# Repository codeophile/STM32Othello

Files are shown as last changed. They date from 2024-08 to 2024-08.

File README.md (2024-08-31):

# STM32 Othello
Play Othello (also known as Reversi) against the computer with selectable levels of difficulty: "Easy" and "Challenging."

## Features

- Easy to build - not many parts
- Uses inexpensive STM32L412 processor.
- You can build my board (I used JLCPCB) or to avoid soldering surface mount, you can breadboard the whole thing using a NUCLEO-L412KB board ($10.99 at Digikey).
- Uses inexpensive ($3.00 on Aliexpress) 8x8 matrix of WS2812B smart LEDs. 
- Playing Othello is very easy to learn as the rules are super simple. Playing well requires strategy.

## Files

- Hardware folder contains schematic, gerbers, and the Eagle project file. Be aware that Eagle project files were created in Eagle 5.x. I'm not sure if it will open OK in newer versions (it should!).
- Software folder contains all the c code and a README for getting started.

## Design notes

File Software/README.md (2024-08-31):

## Options

- You can just flash the STM32L412 chip with the code file named OthelloL412.elf.
- Or, you can edit and debug it since all the source files are included.

## Editing and debugging the code

This code could be adapted for any IDE, but to use it without having to make changes, you'll need to use STM32CubeIDE which is free from ST.com. If your new to this, check out the excellent 4 part YouTube series on titled "Getting Started with STM32 and Nucleo" (https://www.youtube.com/watch?v=hyZS2p1tW-g).

## Steps

- In STMCube32IDE, create a project using: File/New/STM32 Project from an Existing STM32CubeMX Configuration file (.ioc)
	- Browse to the IOC file. (It doesn’t need to be located anywhere special, any folder location will do since a new copy will be made.)
   	- Enter a project name, select the current workspace folder (default) or designate a new one, and create the project. If asked, select “Migrate”.
- Copy the files from the Inc folder in this repository to your project's Core/Inc
- Copy the files from the Src folder in this repository to your project's Core/Src
- Edit the auto-generated Core/Src/main.c:
	- Find comment line containing "USER CODE BEGIN PFP" and insert below it the line:"void APP_Main();"
	- Find comment line containing "USER CODE BEGIN WHILE" and insert below it the line:"APP_Main();"
 - Build the project

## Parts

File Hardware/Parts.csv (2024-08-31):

QTY | Name | Digikey Part | Manufacturer Part | Desc | Price/comments
1 | IC1 | 497-STM32L412K8T6-ND | STM32L412K8T6 | IC MCU 32BIT 64KB FLASH 32LQFP | Was STM32L412KBT6 has 128KB flash
2 | R1-2 | RMCF0805FT10K0CT-ND | RMCF0805FT10K0 | RES 10K OHM 1% 1/8W 0805
1 | R3 | RMCF0805FT249RCT-ND | RMCF0805FT249R | RES 249 OHM 1% 1/8W 0805
6 | C3-5 | 311-1140-1-ND | CC0805KRX7R9BB104 | CAP CER 0.1UF 50V X7R 0805
2 | C1-2 | 1276-1096-1-ND | CL21A106KOQNNNE | CAP CER 10UF 16V X5R 0805
2 |  | A32918-ND | 5-535541-1 | TE Connectivity AMP Connectors | For LED Matrix. 0.265 height more expensive for this $1.16. S7036-ND is $0.37 but .335 height
 |  | S1211EC-40-ND | PRPC040SFAN-RC | CONN HEADER VERT 40POS 2.54MM | Mates with above. Gold plated. Cut post length to fit
1 | H1 | S9169-ND | SBH11-PBPC-D05-ST-BK | CONN HEADER 10POS 2.54MM
1 | SW0 | CKN9565-ND | OS102011MS2QN1 | SWITCH SLIDE SPDT 100MA 12V | Need non-shorting (BBM) end in N1 rather than S1. Can substitute with "C" on the end (high temp resin)
1 | PB0-7 | CKN10880CT-ND | PTS645SL43SMTR92 LFS | SWITCH TACTILE SPST-NO 0.05A 12V
1 | BAT1 | BK-1280-PC6-ND | BK-1280-PC6 | Battery Holder (Open) AA 3 Cell PC Pin
1 | LED Matrix | https://www.aliexpress.us/item/2251832466712520.html
 |  | Many similar boards are available and will work if they are WS2812B LEDs. To fit PCB, look for those with three 0.1 spaced holes near each corner which are used for pwr, gnd, and io
3 | HD107S LEDS | 50-1000pcs HD107S(Similar APA102) LED Chip 5050 2020 RGB Intelligent Control Integrated LED Light Source APA107S Chip 26+kHz PWM - AliExpress 39
 |  | Can substitute SK9822

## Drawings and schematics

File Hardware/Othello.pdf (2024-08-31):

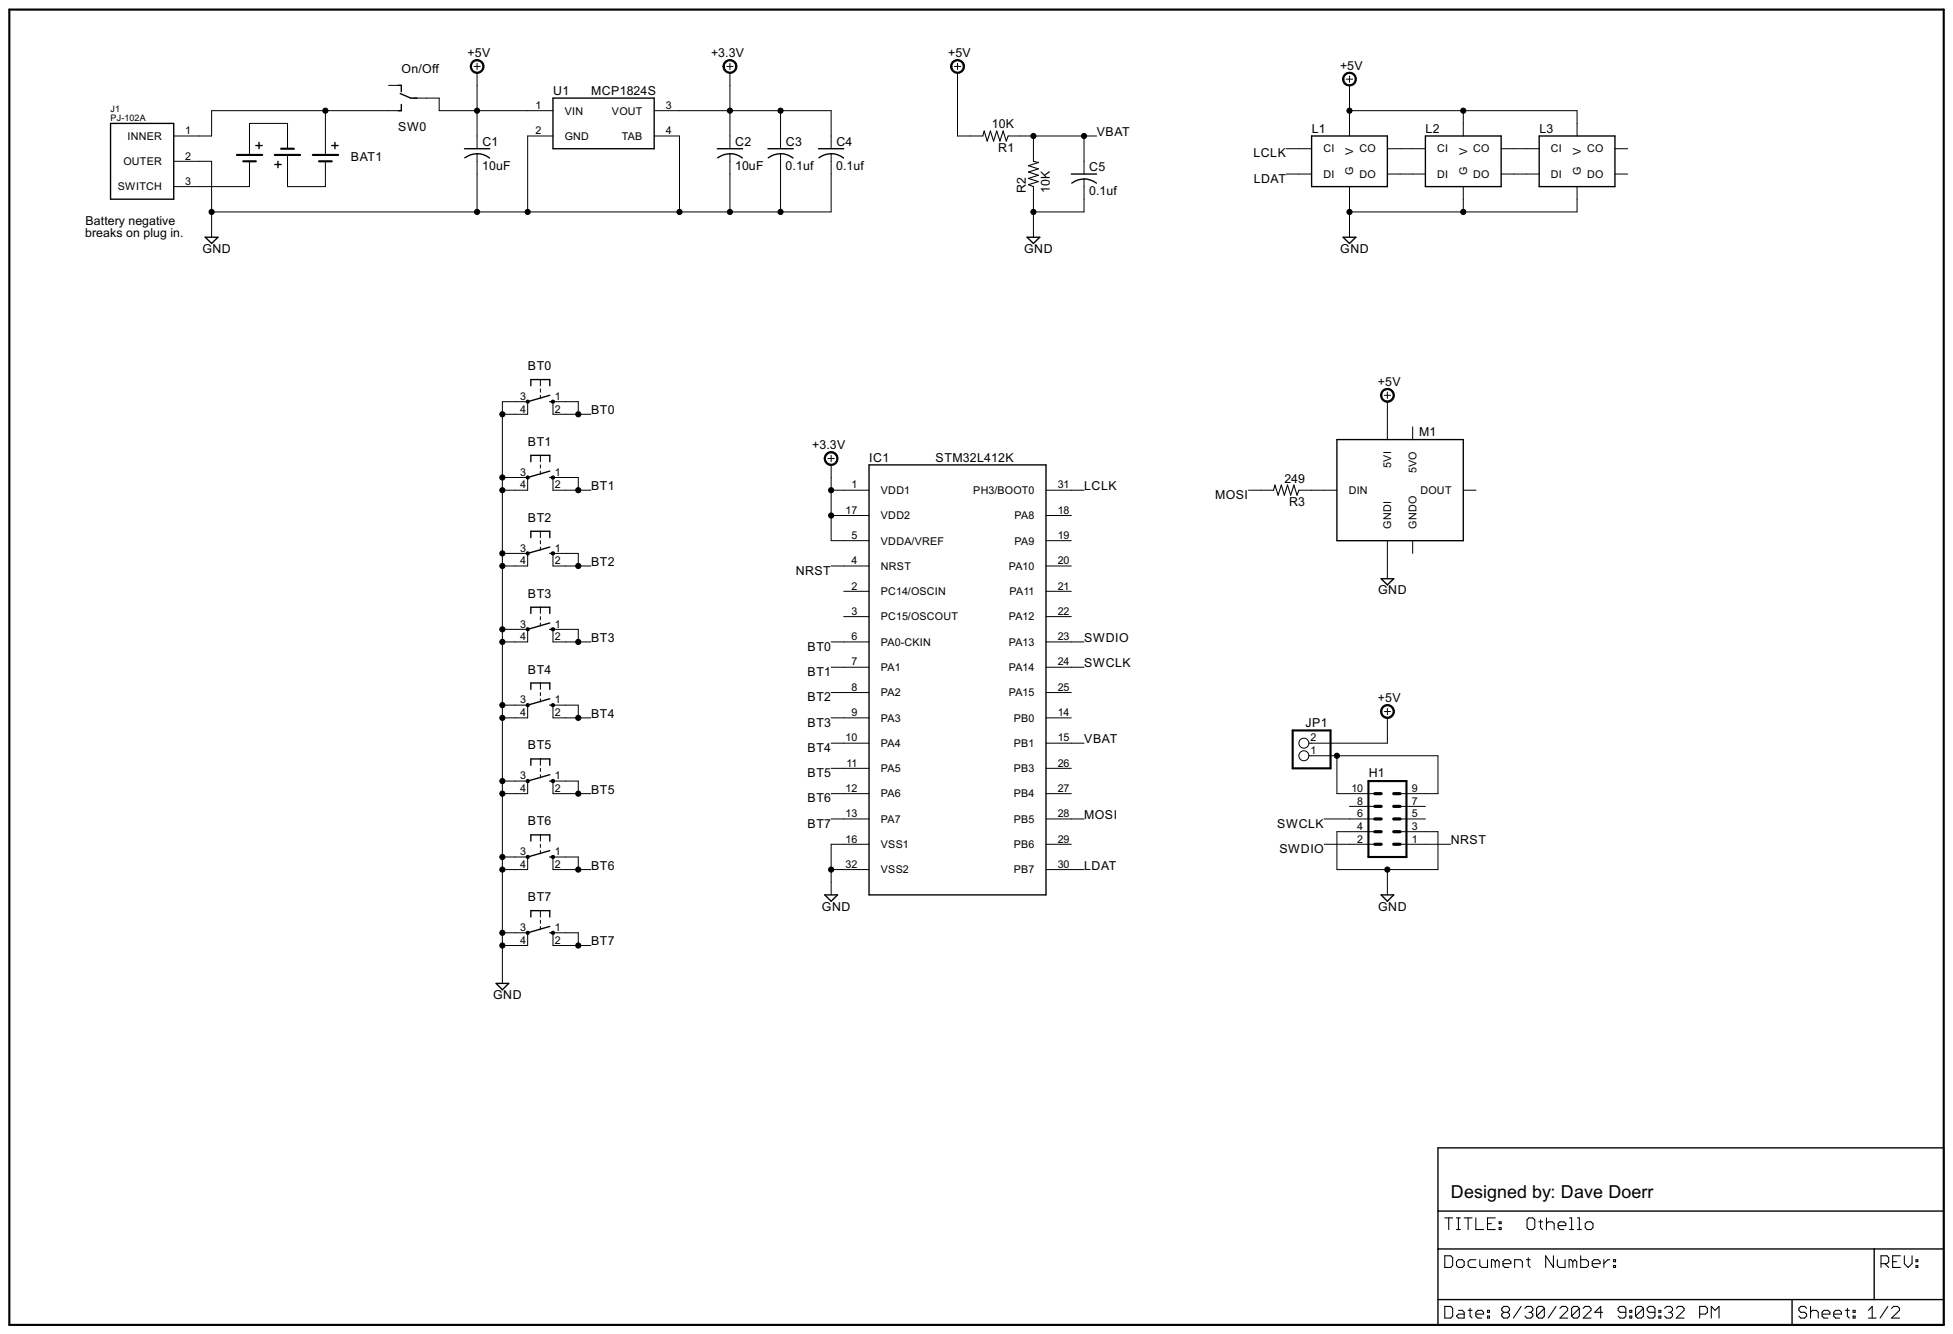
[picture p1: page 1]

Battery negative
breaks on plug in.

Designed by: Dave Doerr

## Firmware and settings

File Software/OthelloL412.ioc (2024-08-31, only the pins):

Mcu.UserName=STM32L412K8Tx
PA0-CK_IN.Signal=GPIO_Input
PA1.Signal=GPIO_Input
PA2.Signal=GPIO_Input
PA3.Signal=GPIO_Input
PA4.Signal=GPIO_Input
PA5.Signal=GPIO_Input
PA6.Signal=GPIO_Input
PA7.Signal=GPIO_Input
PA8.Signal=GPIO_Input
PB1.Signal=ADCx_IN16
PB5.Signal=SPI1_MOSI
PB7.GPIO_Label=LDAT
PB7.Signal=GPIO_Output

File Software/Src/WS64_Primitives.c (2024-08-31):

/********************************************************************************
 WS64_Primitives.c

 WS2812B LED strips using SPI
 MOSI PA7, pin 13

 XMHz works on LED0Byte/LED1Byte
 11 and 12MHz fails on 40/7C
 10MHz=100nS works on 40/7C
 8MHz=125nS works on 40/7C
 6MHz=167nS works on 60/7C and 40/7C
 5MHz=200nS works on 60/70, 7F (stopped checking in-between), note that LED0Byte of 70 (600nS) failed
 5MHz=200nS works on 40/70, 78, 7C, 7E or 7F
 4MHz=250nS works on 40/60, 70, 78, 7C, 7E or 7F, note that LED0Byte of 60 (500nS) failed
 PREFERRED is 5MHz = 200nS, 0H/L is 200/1400 or 400/1200 | 1H/L is 600/1000 to 1400/200

 ********************************************************************************/

#include "APP.h"
#include "main.h"

//WARNING: Don't set MSBit since MOSI idle follows it (odd I know) and
//high idle state causes WS2812B to fail.
//For 5 MHz (80MHz clock, divide by 16 SPI prescaler)
//0H is 200nS, 1H is 1000nS, period is 1600nS
#define LED0Byte 0x40
#define LED1Byte 0x7C;

//For SPI driver
HAL_StatusTypeDef status;
extern SPI_HandleTypeDef hspi1;


//int LEDBuf[8][8];
//int *pLEDBuf = (int*) LEDBuf;

//I determined 10 distinct colors + dark/off = 11 colors
#define COLOR_CNT 11
int colors[COLOR_CNT];

//spiBuf needs 40 bit reset + 3 color bytes for each LED: 40+64*3*8 = 1576
#define SPIBUF_RESET_LEN 40
#define SPIBUF_DATA_LEN 1536
#define SPIBUF_TOTAL_LEN 1576

uchar spiBuf[SPIBUF_TOTAL_LEN];
uchar *pSPIBuf = (uchar*) spiBuf;

//void StoreLEDBuf(); //temporary
//void StoreSPIBuf();
int CutBrightness(int color, uchar factor);

//----------------------------------------------------------------------------------------------------------
void WS64_Init() {

	//INITIALIZE COLORS
	//Stored in G-R-B
	colors[0] = 0x000000; //off
	colors[1] = 0x003200; //red
	colors[2] = 0x143C00; //orange
	colors[3] = 0x202000; //yellow
	colors[4] = 0x301000; //lime
	colors[5] = 0x400000; //green
	colors[6] = 0x340020; //turquoise
	colors[7] = 0x000080; //blue
	colors[8] = 0x001430; //purple
	colors[9] = 0x0D280D; //pink
	colors[10] = 0x282828; //white

	//Reduce brightness
	for (int cnt = 1; cnt < COLOR_CNT; cnt++)
		colors[cnt] = CutBrightness(colors[cnt], 10);

	/*
	//FOR TESTING: Display all colors
	uchar tempForTest[64];
	uchar cX = 1;
	for (int cnt = 0; cnt < 64; cnt++) {
		tempForTest[cnt] = cX++;
		if (cX == 9) cX = 1;
	}
	WS64_Display(tempForTest);
	*/

}

//----------------------------------------------------------------------------------------------------------
int CutBrightness(int color, uchar factor) {

	uchar grn = ByteNofVal(color, 2);
	uchar red = ByteNofVal(color, 1);
	uchar blu = ByteNofVal(color, 0);

	ByteNofVal(color,2)=grn/factor;
	ByteNofVal(color,1)=red/factor;
	ByteNofVal(color,0)=blu/factor;

	return color;
}

//----------------------------------------------------------------------------------------------------------
void WS64_BlankDisplay() {

	uchar *buf = pSPIBuf;

	int count = SPIBUF_RESET_LEN;
	while (count--) {
		*buf++ = 0;
	}

	count = SPIBUF_DATA_LEN;
	while (count--) {
		*buf++ = LED0Byte;
	}
	status = HAL_SPI_Transmit(&hspi1, &spiBuf[0], SPIBUF_TOTAL_LEN, HAL_MAX_DELAY);

}
//----------------------------------------------------------------------------------------------------------
void WS64_Display(uchar *p64ColorIndexes) {

	int bitX;
	uchar *buf = pSPIBuf;
	int color;
	int cnt;

	//Initialize with 50uS reset.
	//At SPI rate of 6MBits, each byte takes 8/6uS = 1.333uS
	//For 50uS reset (hold MOSI low) period, need 50/1.333 = 37.5. Make it 40.
	//Note: measurements by some sources indicate that only about 9uS are actually needed.
	for (cnt = 0; cnt < SPIBUF_RESET_LEN; cnt++) {
		//Stores SPIBUF_RESET_LEN bytes (40)
		*buf++ = 0;
	}
	for (cnt = 0; cnt < 64; cnt++) {
		//Load color from caller's index
		color = colors[*p64ColorIndexes++];
		//Each color requires 24 bits each of which is represented by one spi byte.
		//I tested to make sure that this loop iterates exactly 24 times.
		//Stores 24*64 bytes = 1536.
		for (bitX = 0x800000; bitX != 0; bitX = bitX >> 1) {
			if ((bitX & color) == 0) {
				*buf++ = LED0Byte;
			} else {
				*buf++ = LED1Byte
				;
			}
		}
	}

	//Display using the BLOCKING variant (so fast (~4 mS for 64 LEDs) it doesn't matter)
	status = HAL_SPI_Transmit(&hspi1, &spiBuf[0], SPIBUF_TOTAL_LEN, HAL_MAX_DELAY);

}
